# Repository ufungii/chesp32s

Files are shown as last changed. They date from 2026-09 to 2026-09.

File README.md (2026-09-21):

this summer i found myself forced to play chess online with my friends who were interning in different cities

staring at my computer screen got kind of old, so i decided to stare at a 320x240 LCD ILI9341 instead! 

chesp32s lets me play with my friends whenever, wherever - close or far :) 

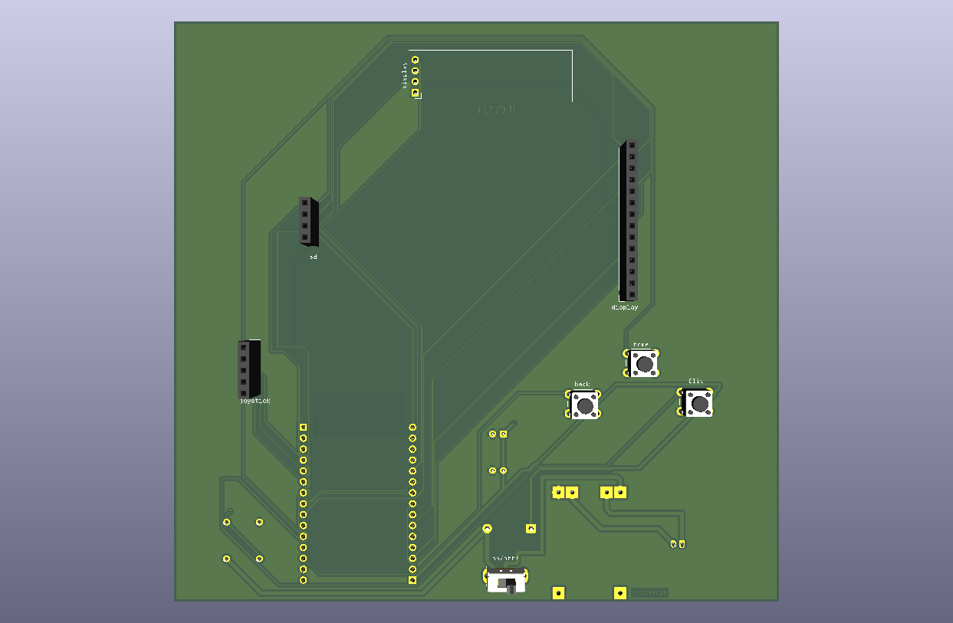
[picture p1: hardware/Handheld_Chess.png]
PCB Render


(the second i assemble this trust and believe the image will be here)

## hardware specs for nerds

* **brain:** ESP32 Dual-Core (Xtensa LX6) @ 240MHz
* **firmware:** C++ / PlatformIO
* **EDA:** KiCad (Schematic + custom footprints + 2-layer PCB)
* **fab:** JLCPCB (new/)
* **board display:** 2.8" ILI9341 320x240 Color TFT over dedicated hardware SPI
* **HUD display:** 0.96" SSD1306 128x64 OLED over I2C
* **inputs:** 2-axis analog joystick (ADC) + push-to-click, plus tactile action switches (`back`, `home`, `flip`)
* **power system:** single-cell LiPo (3.7V nominal, 4.2V max) with onboard USB-C charging via TP4056
* **telemetry:** passive resistor divider to ADC for real-time voltage monitoring & fuel gauging
* **protection:** reverse-polarity / backfeed isolation diode + decoupling filter capacitor bank

## (ﾉ◕ヮ◕)ﾉ*:･ﾟ✧

```text
       [ LiPo Battery (3.7V) ] ──> [ Voltage Divider ] ──> [ ADC Pin ]
                 │
                 ▼
[ USB-C ] ──> [ TP4056 / 3.3V LDO ]
                 │
                 ▼
          [ ESP32 Core ]
         /      |       \
   (SPI)        (I2C)    (Analog/GPIO)
     │            │             │
[ ILI9341 ]  [ SSD1306 ]   [ Joystick & Buttons ]
(Chessboard)    (HUD)        (Move Navigation)
```

## firmwaresque: how do i play?
### game modes

* **pass n play** for when only one person's board is charged: HUD tracks whos turn it is, move history, and board flip can be toggled manually via button
* **solo vs. engine (minimax)** for when you have no friends: the lightweight, onboard chess engine running directly on the ESP32 uses alpha-beta pruning / minimax evaluation to calculate moves locally without needing an internet connection
* **board-to-board (ESP-NOW)** for when both boards are charged: direct wireless peer-to-peer between two `chesp32s` boards over raw ESP-NOW packets. no Wi-Fi router or pairing menus required. just pinging moves directly over 2.4GHz
* **lichess online** for when you're feeling frisky! : connects over Wi-Fi using the Lichess Board API. game events stream over HTTPS/SSE in the background, and moves are dispatched via REST calls so you can play rated matches against friends or randoms from your pocket console

% ### navigation 101 %

## struggles (that i am proud to have overcome) 

* **bus architecture:** driving two separate screens from one ESP32 meant balancing speed and pin budget. squeezing both displays onto one bus was a recipe for sluggish rendering, so the primary ILI9341 runs on dedicated hardware SPI for smooth piece updates, while the secondary status HUD sits on I2C to conserve GPIOs.
* **the LDO brownout incident:** early prototyping was plagued by random board resets because the devboard's stock onboard linear regulator had an absurdly high dropout voltage. the second the LiPo drifted away from a fresh 4.2V charge, the 3.3V power rail would plummet toward ~2.5V, well below the ESP32's brownout detection threshold. i had to audit the power path, factor in quiescent/dropout specs, and implement proper decoupling passives alongside a protection diode to keep the supply rail clean and prevent USB backfeed.
* **battery sensing without frying the ADC:** on that note: i needed real-time fuel-gauge tracking for the LiPo. sitting at ~4.2V when charged (well above the ESP32’s 3.3V pin rating), i calculated and routed an analog resistor voltage divider to step the voltage down safely while minimizing parasitic current draw when idle.
* **datasheets... :** kicad symbols rarely match cheap breakout boards or niche components. as a result, i had to manually measure hardware components, verify mechanical drill tolerances against datasheets, and iteratively debug clearances through JLCDFM rule checks to ensure zero spacing violations before fab.

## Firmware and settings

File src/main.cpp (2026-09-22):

#include <Arduino.h>
#include "display.h"
#include "inputs.h"
#include "game_logic.h"
#include "chess_ai.h"

unsigned long lastBatUpdate = 0;

// Inter-core queues
QueueHandle_t qAIRequest;
QueueHandle_t qAIResponse;
bool isAIThinking = false;

// Task running exclusively on Core 0 for background Minimax calculation
void vAITask(void *pvParameters) {
  int dummy;
  for (;;) {
    if (xQueueReceive(qAIRequest, &dummy, portMAX_DELAY) == pdTRUE) {
      // Depth 2 runs fast (<200ms) without triggering the ESP32 watchdog
      Move best = calculateBestAIMove(2);
      xQueueSend(qAIResponse, &best, portMAX_DELAY);
    }
  }
}

void setup() {
  Serial.begin(115200);
  delay(500);
  Serial.println("Booting ESP32 Chess Console...");

  initBoard();
  initDisplay();
  initInputs();

  // Set default mode to VS_ENGINE for testing
  currentGameMode = GameMode::VS_ENGINE;

  // Create thread-safe message queues
  qAIRequest = xQueueCreate(1, sizeof(int));
  qAIResponse = xQueueCreate(1, sizeof(Move));

  // Launch Engine worker on Core 0 (Core 1 handles display & inputs)
  xTaskCreatePinnedToCore(
    vAITask,
    "AITask",
    8192,
    NULL,
    1,
    NULL,
    0
  );

  drawHomeScreen();
  Serial.println("System Ready! Enjoy the game.");
}

void loop() {
  // 1. If in VS_ENGINE mode and it's Black's turn, trigger Core 0
  if (currentGameMode == GameMode::VS_ENGINE && !isWhiteTurn && !isAIThinking) {
    isAIThinking = true;
    int trigger = 1;
    xQueueSend(qAIRequest, &trigger, 0);
  }

  // 2. Poll for the engine's move without blocking UI
  if (isAIThinking) {
    Move aiMove;
    if (xQueueReceive(qAIResponse, &aiMove, 0) == pdTRUE) {
      if (aiMove.fromX != -1) {
        char piece = board[aiMove.fromY][aiMove.fromX];
        board[aiMove.toY][aiMove.toX] = piece;
        board[aiMove.fromY][aiMove.fromX] = '.';

        // Auto-promote Black pawn to Queen
        if (piece == 'p' && aiMove.toY == 7) {
          board[aiMove.toY][aiMove.toX] = 'q';
        }

        isWhiteTurn = true;
        drawBoard();
      }
      isAIThinking = false;
    }
  } else {
    // 3. Handle player joystick and button inputs
    processInputs();
  }

  // Update battery percentage every 5 seconds
  if (millis() - lastBatUpdate > 5000) {
    lastBatUpdate = millis();
    int pct = getBatteryPercentage();
    drawBatteryIndicator(pct);
  }
}

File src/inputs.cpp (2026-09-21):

#include "inputs.h"
#include "display.h"
#include "game_logic.h"

// Flags for analog deadzone edge-triggering
static bool joyCenteredX = true;
static bool joyCenteredY = true;

bool lastUp = HIGH, lastDown = HIGH, lastLeft = HIGH, lastRight = HIGH;
bool lastSel = HIGH, lastOpt1 = HIGH, lastBack = HIGH, lastOpt2 = HIGH;

unsigned long bootTime = 0;

void initInputs() {
    pinMode(JOY_SW_PIN, INPUT_PULLUP);
    pinMode(BTN_OPT1, INPUT_PULLUP);
    pinMode(BTN_BACK, INPUT_PULLUP);
    pinMode(BTN_OPT2, INPUT_PULLUP);

    analogSetPinAttenuation(JOY_X_PIN, ADC_11db);
    analogSetPinAttenuation(JOY_Y_PIN, ADC_11db);

    bootTime = millis();

    // ADC configuration for battery sensing
  analogReadResolution(12);
  analogSetAttenuation(ADC_11db);
}

int getBatteryPercentage() {
  int rawSum = 0;
  for (int i = 0; i < 10; i++) {
    rawSum += analogRead(BAT_SENSE_PIN);
    delay(2);
  }
  float rawAvg = rawSum / 10.0;

  // ESP32 ADC full-scale reference is typically ~3.3V, but internal Vref varies (often 3.1V - 3.3V)
  // Multiply by 2.0 to account for the 100k:100k divider
  float batVoltage = (rawAvg / 4095.0) * 3.3 * 2.0;

  // Usable LiPo discharge curve: 3.4V (0%) to 4.2V (100%)
  int pct = (int)(((batVoltage - 3.4) / (4.2 - 3.4)) * 100.0);
  return constrain(pct, 0, 100);
}

void processInputs() {
    // Read raw ADC values
    int rawX = analogRead(JOY_X_PIN);
    int rawY = analogRead(JOY_Y_PIN);

    // Default virtual D-pad buttons to HIGH (unpressed)
    bool curLeft  = HIGH;
    bool curRight = HIGH;
    bool curUp    = HIGH;
    bool curDown  = HIGH;

    // Horizontal axis edge detection
    if (rawX < JOY_THRESH_LOW) {
        if (joyCenteredX) {
            curLeft = LOW;
            joyCenteredX = false;
        }
    } else if (rawX > JOY_THRESH_HIGH) {
        if (joyCenteredX) {
            curRight = LOW;
            joyCenteredX = false;
        }
    } else {
        joyCenteredX = true; // Returned to deadzone
    }

    // Vertical axis edge detection
    if (rawY < JOY_THRESH_LOW) {
        if (joyCenteredY) {
            curUp = LOW;
            joyCenteredY = false;
        }
    } else if (rawY > JOY_THRESH_HIGH) {
        if (joyCenteredY) {
            curDown = LOW;
            joyCenteredY = false;
        }
    } else {
        joyCenteredY = true; // Returned to deadzone
    }

    // Read physical buttons (Joystick switch is mapped to BTN_SEL)
    bool curSel  = digitalRead(JOY_SW_PIN);
    bool curOpt1 = digitalRead(BTN_OPT1);
    bool curBack = digitalRead(BTN_BACK);
    bool curOpt2 = digitalRead(BTN_OPT2);

    if (millis() - bootTime < 300) {
        lastUp = curUp; lastDown = curDown; lastLeft = curLeft; lastRight = curRight;
        lastSel = curSel; lastOpt1 = curOpt1; lastBack = curBack; lastOpt2 = curOpt2;
        return;
    }

    // --- GLOBAL BACK KEY (`BACK` / GPIO 33) ---
    if (lastBack == HIGH && curBack == LOW) {
        if (currentState != STATE_MENU) {
            currentState = STATE_MENU;
            drawHomeScreen();
            delay(100);
            return;
        }
    }

    // --- MENU STATE ---
    if (currentState == STATE_MENU) {
        if (lastUp == HIGH && curUp == LOW)     updateMenuSelection(menuSelection - 1);
        if (lastDown == HIGH && curDown == LOW) updateMenuSelection(menuSelection + 1);

        if (lastSel == HIGH && curSel == LOW) {
            currentState = (GameState)(menuSelection + 1);
            drawBoard();
        }
    }
    // --- CHESS BOARD STATE ---
    else {
        if (lastUp == HIGH && curUp == LOW) {
            int newY = constrain(selY - 1, 0, 7);
            drawSquare(selX, selY, false); selY = newY; drawSquare(selX, selY, true);
        }
        if (lastDown == HIGH && curDown == LOW) {
            int newY = constrain(selY + 1, 0, 7);
            drawSquare(selX, selY, false); selY = newY; drawSquare(selX, selY, true);
        }
        if (lastLeft == HIGH && curLeft == LOW) {
            int newX = constrain(selX - 1, 0, 7);
            drawSquare(selX, selY, false); selX = newX; drawSquare(selX, selY, true);
        }
        if (lastRight == HIGH && curRight == LOW) {
            int newX = constrain(selX + 1, 0, 7);
            drawSquare(selX, selY, false); selX = newX; drawSquare(selX, selY, true);
        }

        // Action 1: Select / Move (Click joystick stick down)
        if (lastSel == HIGH && curSel == LOW) {
            handleAction();
        }

        // Action 2: Cancel / Deselect
        if (lastOpt1 == HIGH && curOpt1 == LOW) {
            if (sourceX != -1 || sourceY != -1) {
                int oldX = sourceX, oldY = sourceY;
                sourceX = -1;
                sourceY = -1;
                drawSquare(oldX, oldY, false);
                drawSquare(selX, selY, true);
                Serial.println("Selection Canceled");
            }
        }

        // Track button hold duration on BTN_OPT2
        static unsigned long opt2PressTime = 0;
        static bool opt2Held = false;

        if (lastOpt2 == HIGH && curOpt2 == LOW) {
            opt2PressTime = millis();
            opt2Held = false;
        }

        // If held for > 1000ms: RESTART GAME
        if (curOpt2 == LOW && !opt2Held && (millis() - opt2PressTime > 1000)) {
            opt2Held = true;
            initBoard();
            sourceX = -1; sourceY = -1;
            drawBoard();
            Serial.println("Long press: Game Restarted!");
        }

        // Quick tap: FLIP BOARD
        if (lastOpt2 == LOW && curOpt2 == HIGH) {
            if (!opt2Held) {
                Serial.println("Short press: Flip Board triggered");
            }
        }
    }

    lastUp    = curUp;
    lastDown  = curDown;
    lastLeft  = curLeft;
    lastRight = curRight;
    lastSel   = curSel;
    lastOpt1  = curOpt1;
    lastBack  = curBack;
    lastOpt2  = curOpt2;
}

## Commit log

2026-08-20 Feat: Complete 8-button input mapping and touch selection logic
2026-08-23 Feat: Add pawn promotion and fix display issues
    [inputs.cpp, main.cpp]
2026-09-05 Feat: Map menu and board navigation to analog joystick and sw click
2026-09-21 Feat: Add v2 PCB hardware design, schematic preview, and battery monitoring
    [Handheld_Chess-B_Cu.gbl, Handheld_Chess-B_Mask.gbs, Handheld_Chess-B_Paste.gbp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]
2026-09-22 Feat: Tightened up Minimax engine worker capabilities
    [main.cpp]
